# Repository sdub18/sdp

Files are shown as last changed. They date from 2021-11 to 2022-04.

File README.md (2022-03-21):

# Senior Design Project UMass Electrical and Computer Engineering - Team 23
Motor Health Analytics and Feedback Dashboard
Sam DuBois, Andres Gutierrez, Andrew Tran, and Michael Brauninger

Packages Necessary to Download to Run Arduino Code
- Adafruit MCP9808
- Adafruit LIS3DH
- Adafruit INA260
- ArduinoJSON6




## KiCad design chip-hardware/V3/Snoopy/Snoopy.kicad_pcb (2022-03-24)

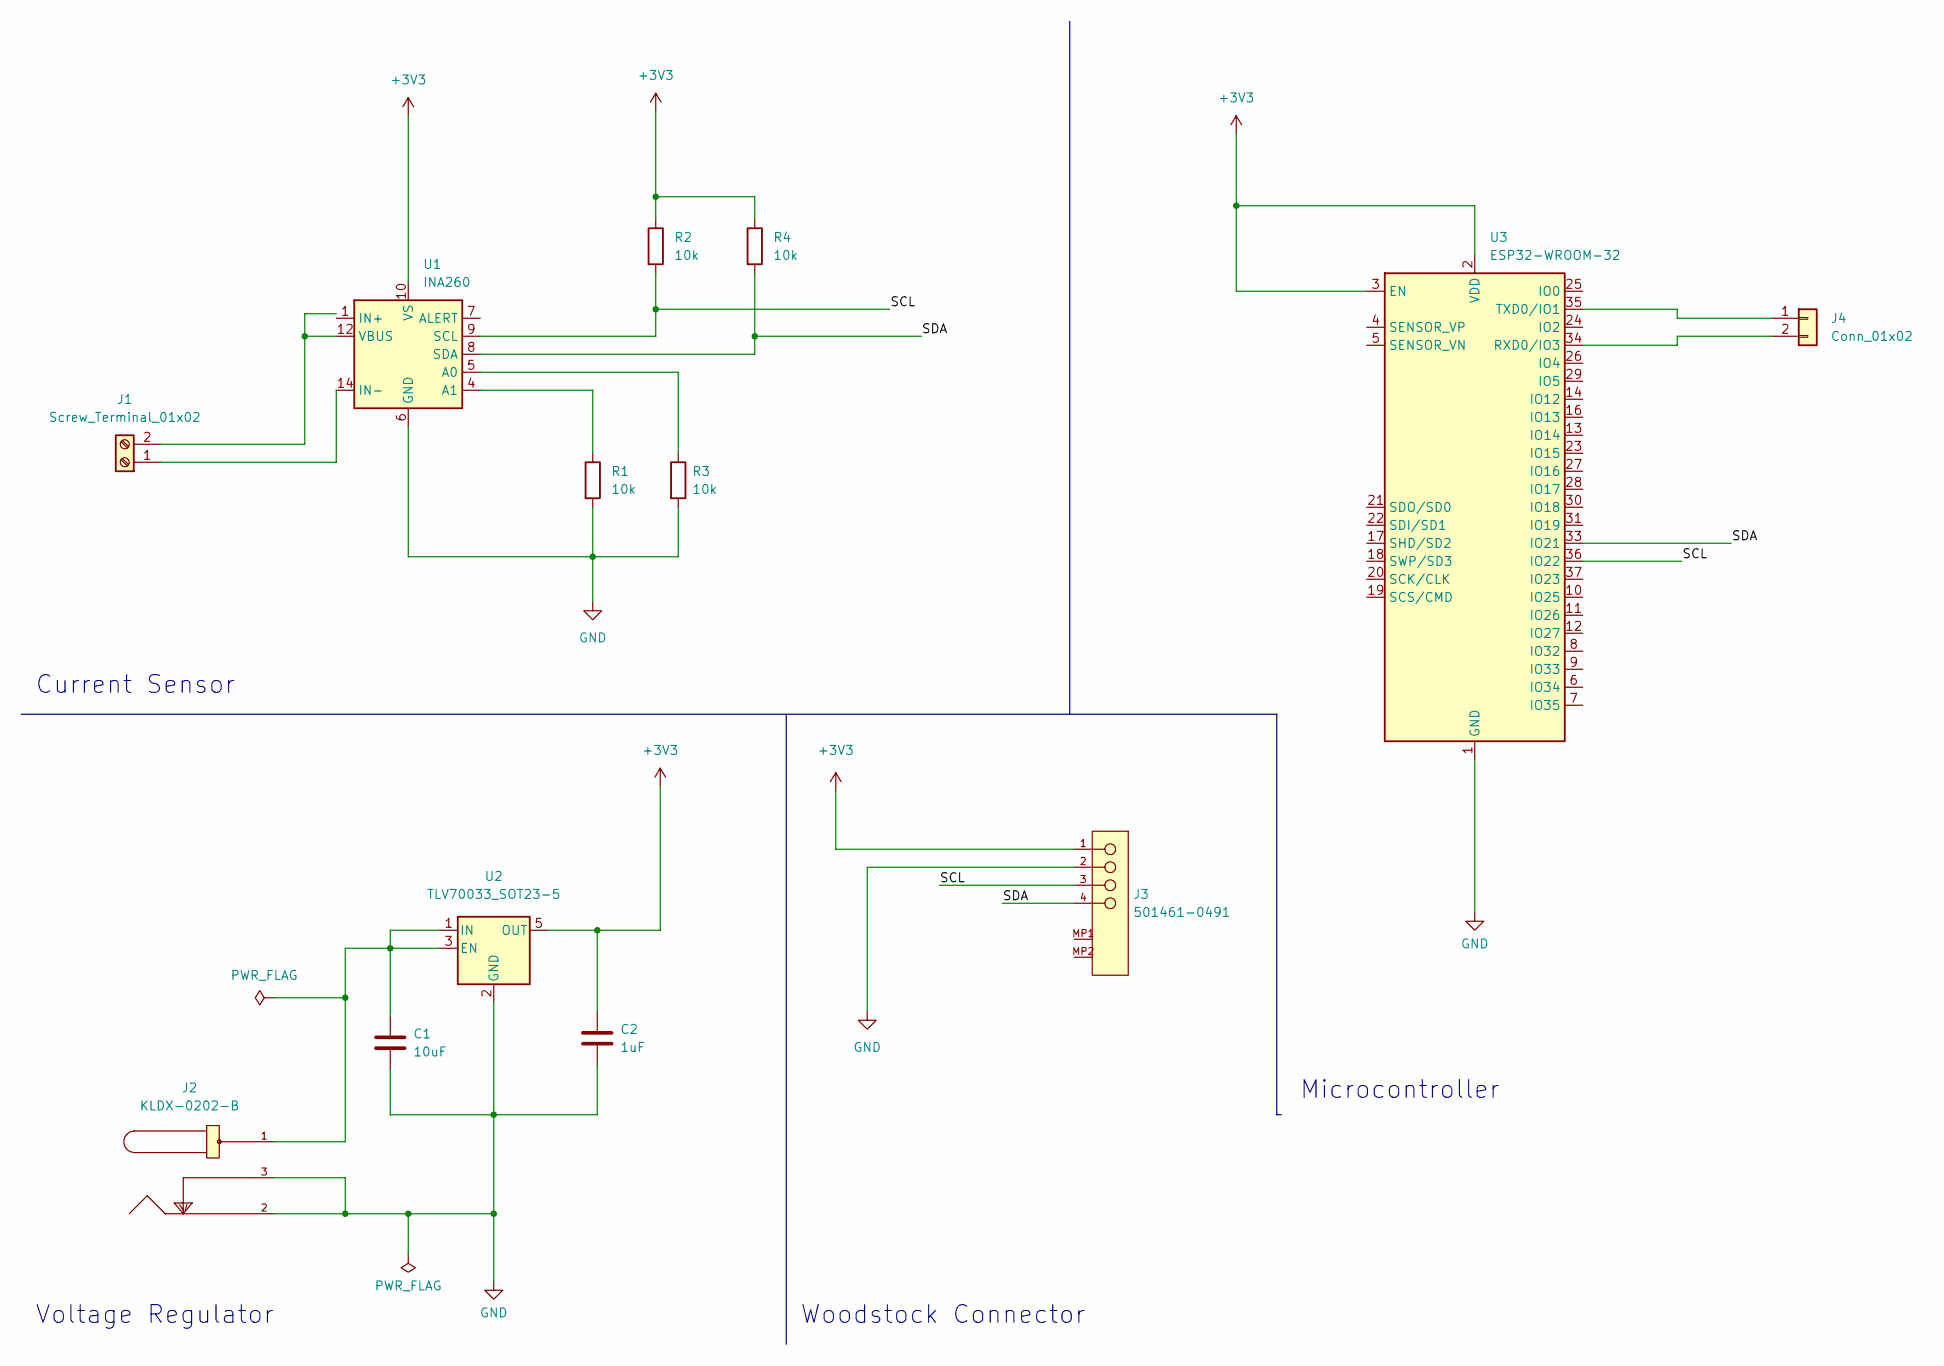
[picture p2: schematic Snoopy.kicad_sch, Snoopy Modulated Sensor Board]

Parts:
C1: 10uF; C_0603_1608Metric_Pad1.08x0.95mm_HandSolder
C2: 1uF; C_0603_1608Metric_Pad1.08x0.95mm_HandSolder
J1: Screw_Terminal_01x02; TerminalBlock_RND_205-00232_1x02_P5.08mm_Horizontal
J2: KLDX-0202-B; Kycon-KLDX-0202-B-MFG; current rating 3.5A; voltage rating 24V; mouser part number 806-KLDX-0202-B; digikey description CONN PWR JACK 2.5X5.5MM SOLDER
J3: 501461-0491; Molex-501461-0491-Manufacturer_Recommended; Voltage Max 50V AC (RMS)/DC
J4: Conn_01x02; SolderWire-0.1sqmm_1x02_P3.6mm_D0.4mm_OD1mm
R1, R2, R3, R4: 10k; R_0603_1608Metric_Pad0.98x0.95mm_HandSolder
U1: INA260; TSSOP-16_4.4x5mm_P0.65mm
U2: TLV70033_SOT23-5; SOT-23-5
U3: ESP32-WROOM-32

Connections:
+3V3: C2.1, J3.1, R2.1, R4.1, U1.10 (VS), U2.5 (OUT), U3.2 (VDD), U3.3 (EN)
/SCL: J3.3, R2.2, U1.9 (SCL), U3.36 (IO22)
/SDA: J3.4, R4.2, U1.8 (SDA), U3.33 (IO21)
GND: C1.2, C2.2, J2.2, J2.3, J3.2, R1.2, R3.2, U1.6 (GND), U1.11 (GND), U2.2 (GND), U3.1 (GND), U3.15 (GND), U3.38 (GND), U3.39 (GND)
unnamed: C1.1, J2.1, U2.1 (IN), U2.3 (EN)
unnamed: J1.1, U1.14 (IN-), U1.15 (IN-), U1.16 (IN-)
unnamed: J1.2, U1.12 (VBUS)
unnamed: J4.1, U3.35 (TXD0/IO1)
unnamed: J4.2, U3.34 (RXD0/IO3)
unnamed: R1.1, U1.4 (A1)
unnamed: R3.1, U1.5 (A0)
unnamed: U1.1 (IN+), U1.2 (IN+), U1.3 (IN+)

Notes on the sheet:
Voltage Regulator
Woodstock Connector
Microcontroller
Current Sensor

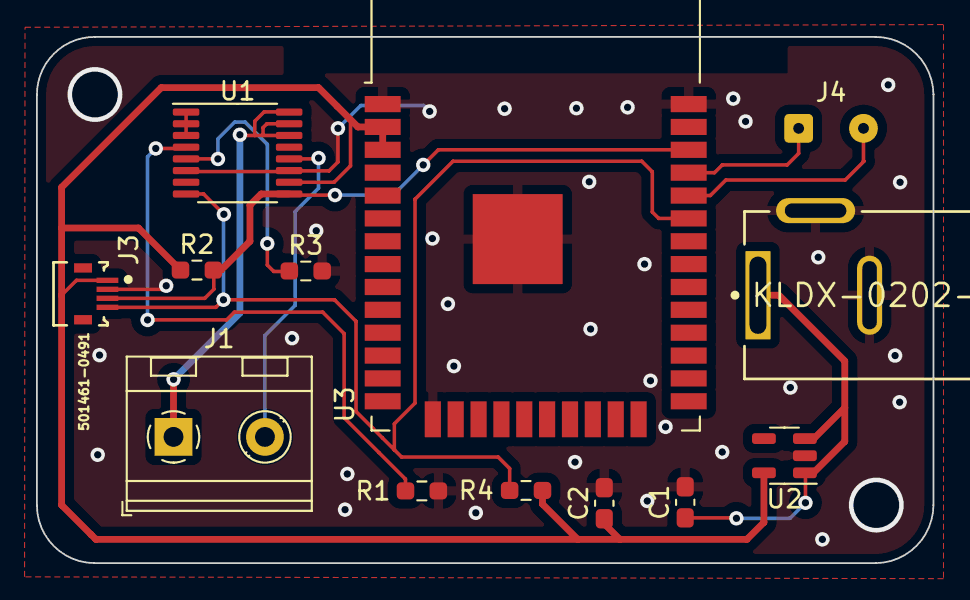
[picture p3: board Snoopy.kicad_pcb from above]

Board: 2 copper layers, 49.8 x 29.2 mm, 13 parts (0 on the bottom side), 12 nets.

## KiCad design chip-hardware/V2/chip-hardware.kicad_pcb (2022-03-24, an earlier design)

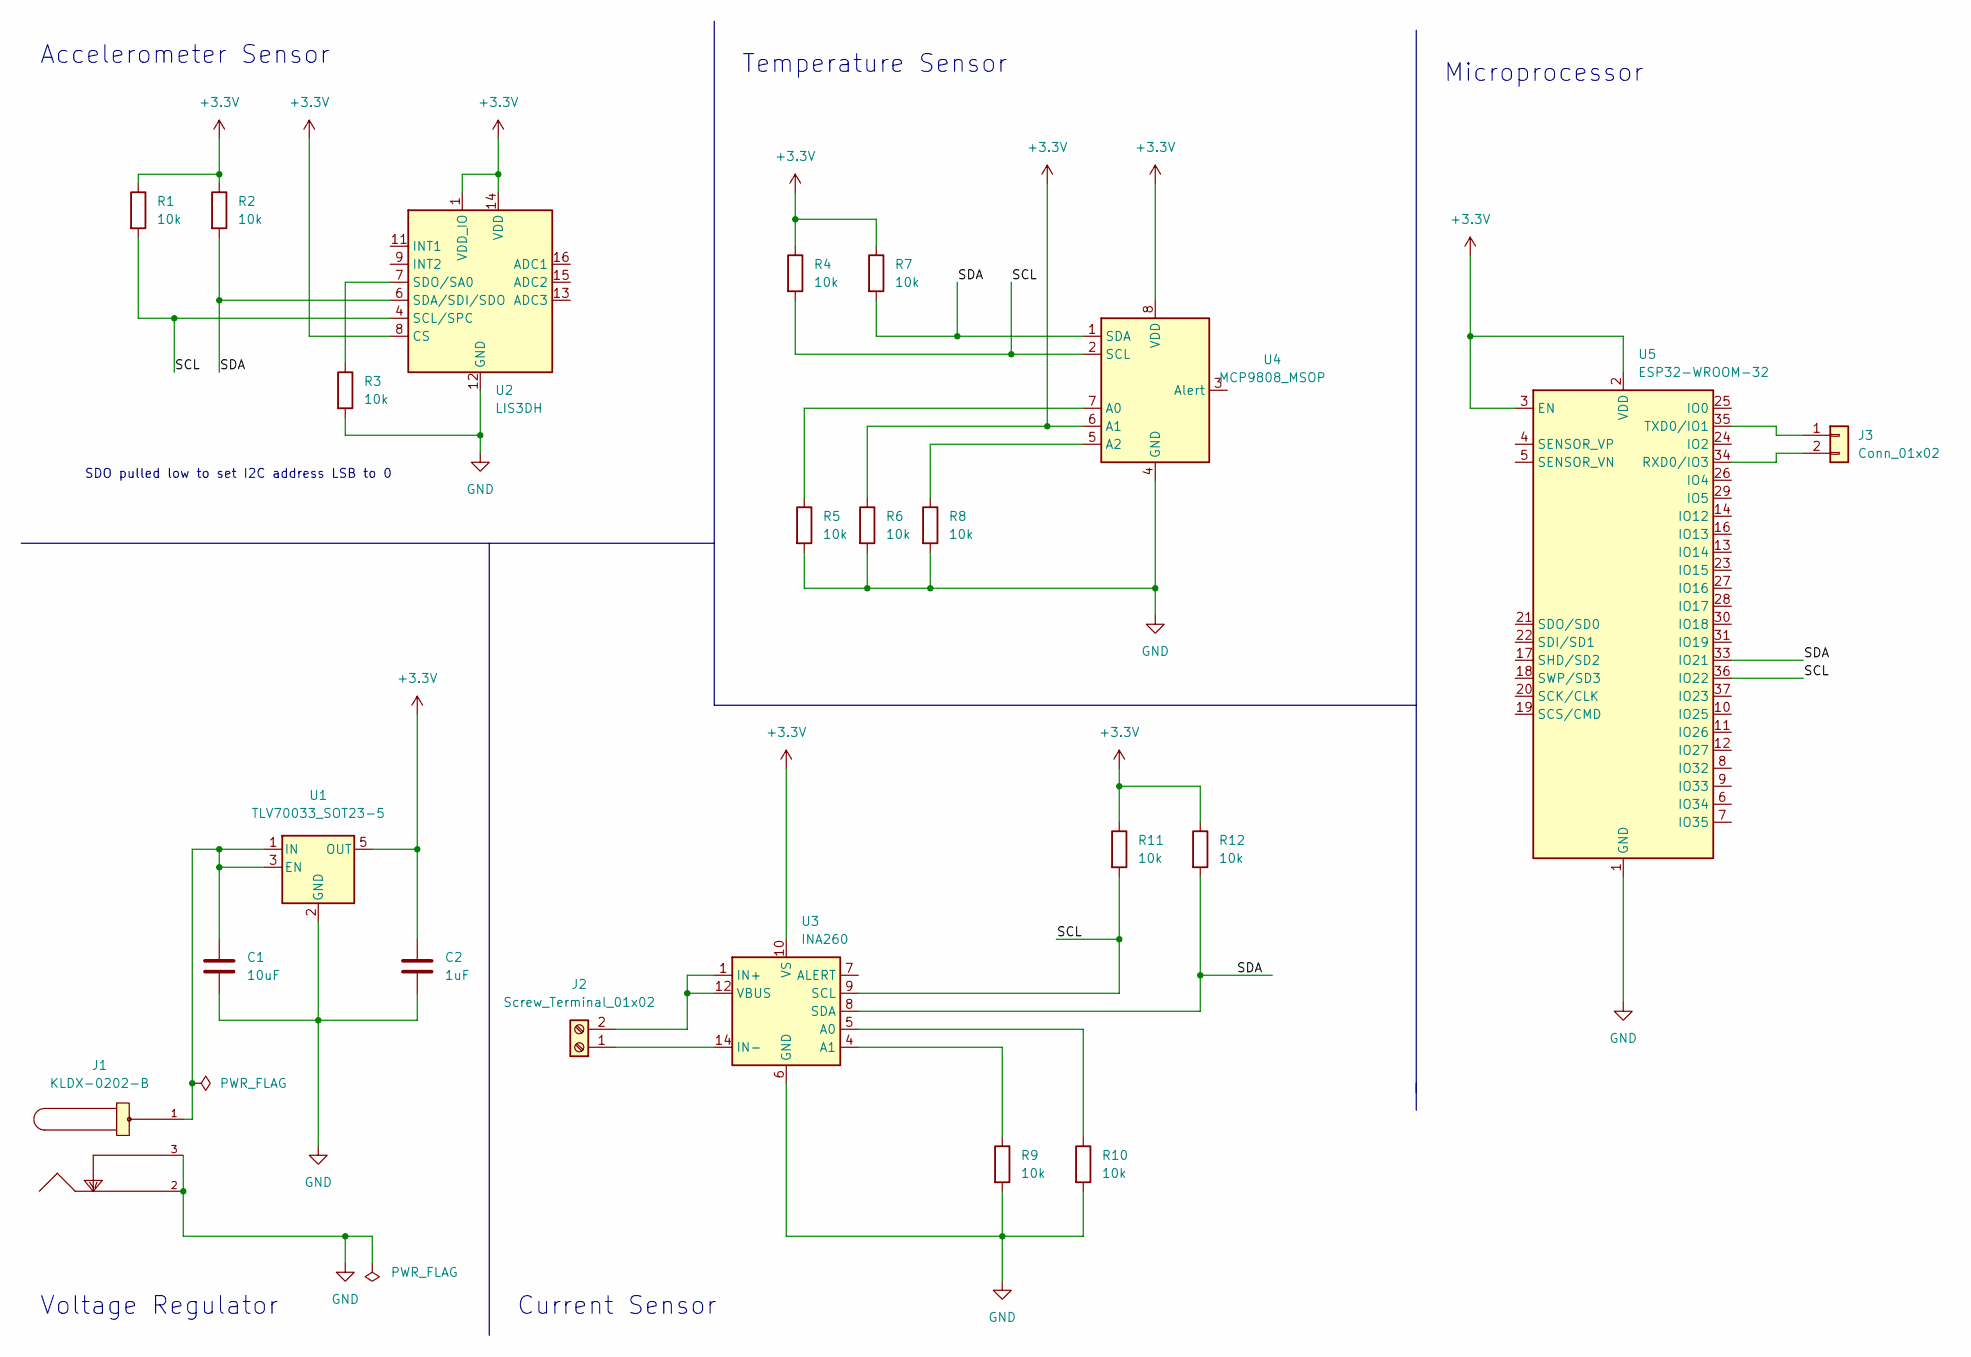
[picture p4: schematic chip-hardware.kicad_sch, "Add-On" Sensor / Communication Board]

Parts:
C1: 10uF; C_0603_1608Metric_Pad1.08x0.95mm_HandSolder
C2: 1uF; C_0603_1608Metric_Pad1.08x0.95mm_HandSolder
J1: KLDX-0202-B; Kycon-KLDX-0202-B-MFG; current rating 3.5A; voltage rating 24V; mouser part number 806-KLDX-0202-B; digikey description CONN PWR JACK 2.5X5.5MM SOLDER
J2: Screw_Terminal_01x02; TerminalBlock_RND_205-00232_1x02_P5.08mm_Horizontal
J3: Conn_01x02; SolderWire-0.1sqmm_1x02_P3.6mm_D0.4mm_OD1mm
R1, R2, R3, R4, R5, R6, R7, R8, R9, R10, R11, R12: 10k; R_0603_1608Metric_Pad0.98x0.95mm_HandSolder
U1: TLV70033_SOT23-5; SOT-23-5
U2: LIS3DH; LGA-16_3x3mm_P0.5mm_LayoutBorder3x5y
U3: INA260; TSSOP-16_4.4x5mm_P0.65mm
U4: MCP9808_MSOP; MSOP-8_3x3mm_P0.65mm
U5: ESP32-WROOM-32

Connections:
+3V3: C2.1, R1.1, R2.1, R4.1, R6.1, R7.1, R11.1, R12.1, U1.5 (OUT), U2.1 (VDD_IO), U2.8 (CS), U2.14 (VDD), U3.10 (VS), U4.6 (A1), U4.8 (VDD), U5.2 (VDD), U5.3 (EN)
/SCL: R1.2, R4.2, R11.2, U2.4 (SCL/SPC), U3.9 (SCL), U4.2 (SCL), U5.36 (IO22)
/SDA: R2.2, R7.2, R12.2, U2.6 (SDA/SDI/SDO), U3.8 (SDA), U4.1 (SDA), U5.33 (IO21)
GND: C1.2, C2.2, J1.2, J1.3, R3.2, R5.2, R6.2, R8.2, R9.2, R10.2, U1.2 (GND), U2.5 (GND), U2.10 (GND), U2.12 (GND), U3.6 (GND), U3.11 (GND), U4.4 (GND), U5.1 (GND), U5.15 (GND), U5.38 (GND), U5.39 (GND)
unnamed: C1.1, J1.1, U1.1 (IN), U1.3 (EN)
unnamed: J2.1, U3.14 (IN-), U3.15 (IN-), U3.16 (IN-)
unnamed: J2.2, U3.1 (IN+), U3.2 (IN+), U3.3 (IN+), U3.12 (VBUS)
unnamed: J3.1, U5.35 (TXD0/IO1)
unnamed: J3.2, U5.34 (RXD0/IO3)
unnamed: R3.1, U2.7 (SDO/SA0)
unnamed: R5.1, U4.7 (A0)
unnamed: R8.1, U4.5 (A2)
unnamed: R9.1, U3.4 (A1)
unnamed: R10.1, U3.5 (A0)

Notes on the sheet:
Current Sensor
Temperature Sensor
Microprocessor
Accelerometer Sensor
Voltage Regulator
SDO pulled low to set I2C address LSB to 0

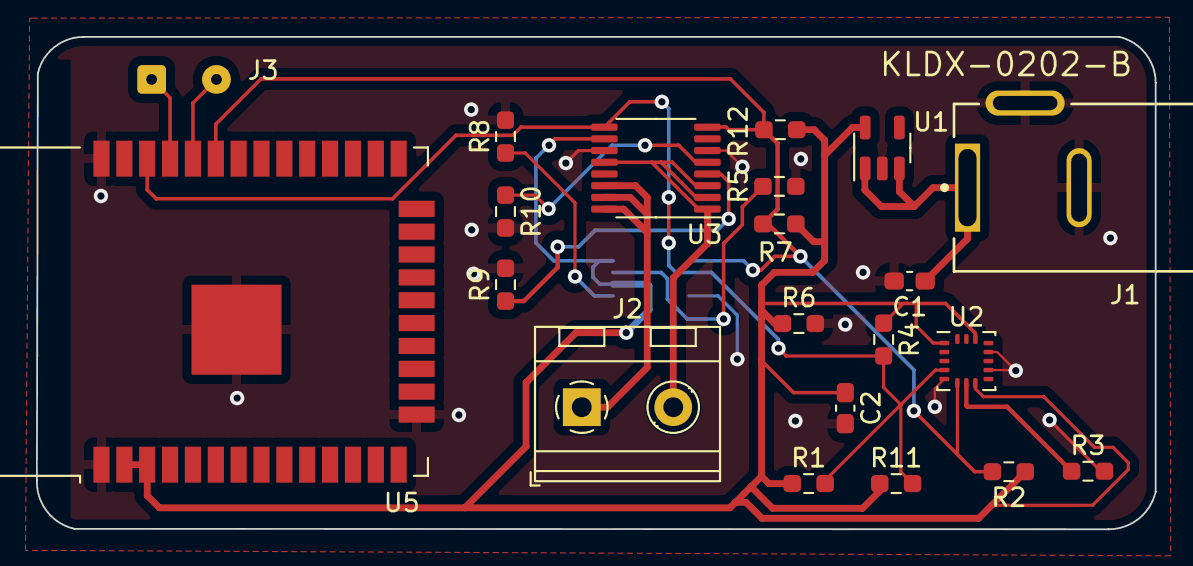
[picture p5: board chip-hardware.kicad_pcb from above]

Board: 2 copper layers, 62.2 x 27.4 mm, 22 parts (1 on the bottom side), 14 nets.

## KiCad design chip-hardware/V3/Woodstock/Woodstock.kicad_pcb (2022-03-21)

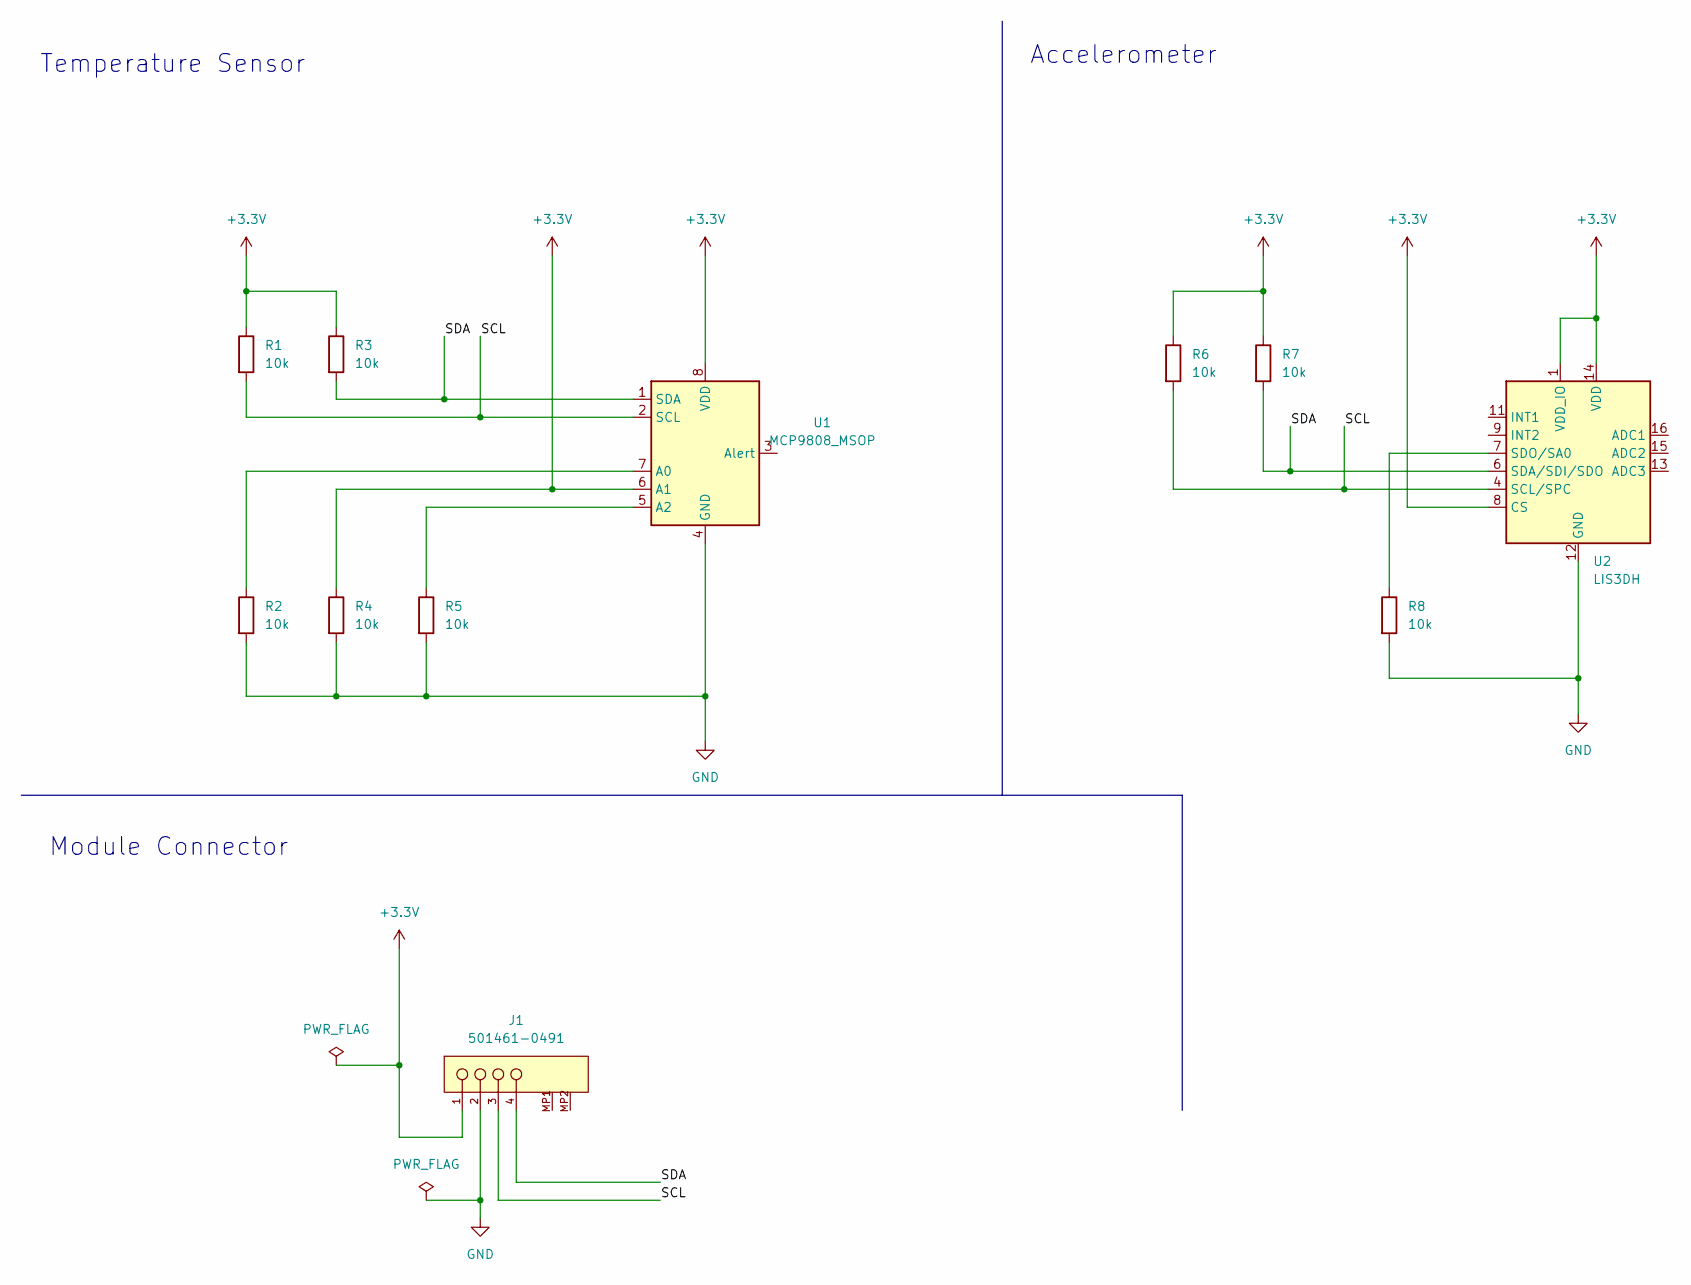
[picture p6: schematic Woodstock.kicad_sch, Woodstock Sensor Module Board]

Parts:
J1: 501461-0491; Molex-501461-0491-Manufacturer_Recommended; Voltage Max 50V AC (RMS)/DC
R1, R2, R3, R4, R5, R6, R7, R8: 10k; R_0603_1608Metric_Pad0.98x0.95mm_HandSolder
U1: MCP9808_MSOP; MSOP-8_3x3mm_P0.65mm
U2: LIS3DH; LGA-16_3x3mm_P0.5mm_LayoutBorder3x5y

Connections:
+3V3: J1.1, R1.1, R3.1, R4.1, R6.1, R7.1, U1.6 (A1), U1.8 (VDD), U2.1 (VDD_IO), U2.8 (CS), U2.14 (VDD)
/SCL: J1.3, R1.2, R6.2, U1.2 (SCL), U2.4 (SCL/SPC)
/SDA: J1.4, R3.2, R7.2, U1.1 (SDA), U2.6 (SDA/SDI/SDO)
GND: J1.2, R2.2, R4.2, R5.2, R8.2, U1.4 (GND), U2.5 (GND), U2.10 (GND), U2.12 (GND)
unnamed: R2.1, U1.7 (A0)
unnamed: R5.1, U1.5 (A2)
unnamed: R8.1, U2.7 (SDO/SA0)

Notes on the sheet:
Module Connector
Temperature Sensor
Accelerometer

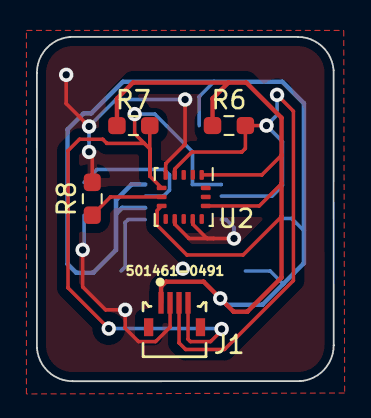
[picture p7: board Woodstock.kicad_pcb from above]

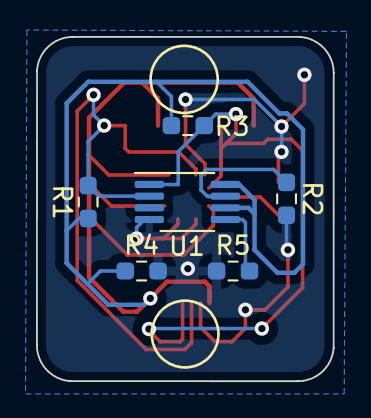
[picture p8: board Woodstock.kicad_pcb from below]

Board: 2 copper layers, 16.5 x 19.1 mm, 11 parts (6 on the bottom side), 7 nets.

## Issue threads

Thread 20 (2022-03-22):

Power Issue with Chip

sdub18, 2022-03-22:
Figure out why power readings were sometimes going to zero

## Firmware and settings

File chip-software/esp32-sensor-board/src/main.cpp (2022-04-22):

#include <Arduino.h>
#include <WiFi.h>
#include <Wire.h>
#include <Adafruit_MCP9808.h>
#include <Adafruit_LIS3DH.h>
#include <Adafruit_Sensor.h>
#include <Adafruit_INA260.h>
#include <ArduinoJson.h>
#include <StreamUtils.h>

const char* SSID = "Pixel_8846";   
const char* PASS = "andtran123";
const char* HOST = "192.168.180.57"; // change to ip address of host computer

const uint16_t PORT = 49160;
const uint16_t UID = 1;

uint16_t prevDay = 0;
bool canSend = false;
uint16_t sampleRate = 100;
// Json Document
StaticJsonDocument<16> id_pkt;
StaticJsonDocument<192> data_pkt;
JsonObject data = data_pkt.createNestedObject("data"); 
JsonObject acceleration = data.createNestedObject("acceleration");

// Connected Devices
Adafruit_LIS3DH lis3dh = Adafruit_LIS3DH();            // Accelerometer sensor
Adafruit_MCP9808 mcp9808 = Adafruit_MCP9808();   // Temperature Sensor
Adafruit_INA260 ina260 = Adafruit_INA260();         // Current Sensor

// WiFi Client to communicate with
WiFiClient client;
/////////////////////////////////////////////////////////////////////////////
// ------------------------- HELPER FUNCTIONS -----------------------------//
/////////////////////////////////////////////////////////////////////////////

void fetch_NTP() {
  configTime(0, 0, "pool.ntp.org");
}

int64_t get_timestamp() {
	struct timeval tv;
	gettimeofday(&tv, NULL);
	return (tv.tv_sec * 1000LL + (tv.tv_usec / 1000LL));
}

bool check_new_day(uint16_t *prev_day) {
  struct timeval tv;
	gettimeofday(&tv, NULL);
  int t = tv.tv_sec / 86400 ;
  if (t != *prev_day) {
    *prev_day = t;
    fetch_NTP();
    return true;
  }
  return false;
}

void create_packet() {
  // ---------- META DATA ------------------
  data_pkt["id"] = UID;
  data_pkt["timestamp"] = get_timestamp();

  // ---------- ACCELEROMETER ------------
  lis3dh.read();
  acceleration["x"] = lis3dh.x;
  acceleration["y"] = lis3dh.y;
  acceleration["z"] = lis3dh.z;


  // ----------- TEMPERATURE --------------
  data["temp"] = mcp9808.readTempF();
  
  // ------------- CURRENT ----------------
  data["current"] = ina260.readCurrent();
  data["voltage"] = ina260.readBusVoltage();
  data["power"] = ina260.readPower();

}


/////////////////////////////////////////////////////////////////////////////
// -------------------------- INITIAL SETUP -------------------------------//
/////////////////////////////////////////////////////////////////////////////


void setup() {
  // -------------------- SERIAL COMMUNICATIONS -----------------------
  Serial.begin(115200);
  while (!Serial) delay(1);

  id_pkt["id"] = UID;  

  // -------------------- WIFI CONNECTION -----------------------------
  WiFi.begin(SSID, PASS);
  while (WiFi.status() != WL_CONNECTED) {
      delay(500);
      Serial.println("Connecting to WiFi...");
  }
  Serial.println("Connected to the WiFi network");

  fetch_NTP(); // initialize time 

  // ------------------------ ACCELEROMETER -------------------------

  if (! lis3dh.begin(0x19)) {   // change this to 0x19 for alternative i2c address
    Serial.println("Could not start LIS3DH");
    while (1) yield();
  } else {
    Serial.println("LIS3DH started");
  }

  // ------------------------ TEMPERATURE ------------------------------
  
  if (!mcp9808.begin(0x1A)) {
    Serial.println("Could not start MCP9808");
    while (1);
  } else {
    Serial.println("MCP9808 started");
  }
  mcp9808.wake();
  mcp9808.setResolution(3); // sets the resolution mode of reading, the modes are defined in the table bellow:
  // Mode Resolution SampleTime
  //  0    0.5°C       30 ms
  //  1    0.25°C      65 ms
  //  2    0.125°C     130 ms
  //  3    0.0625°C    250 ms

  // --------------------------- CURRENT ------------------------------

  if (!ina260.begin()) {
    Serial.println("Could not start INA260");
    while (1);
  } else {
    Serial.println("INA260 started");
  }
  
}

/////////////////////////////////////////////////////////////////////////////
// ---------------------------- MAIN LOOP ---------------------------------//
/////////////////////////////////////////////////////////////////////////////

void loop() {

  if (client.connected()){
    // ------ check if new day -------------
    check_new_day(&prevDay);

    // ------ Check if server sent ACK ------
    if (client.available()) {
      if (!canSend){
        char c = client.read(); 
        if (c == 0x01) canSend = true;
      } else {
        char low = client.read();
        char high = client.read();
        sampleRate = (high << 8) | low;
      }
    }

    // -------- Communicate Results ---------
    WriteBufferingStream buffered_client(client, 192);
    if (canSend) {
      create_packet();
      serializeJson(data_pkt, Serial);
      Serial.println("");
      serializeJson(data_pkt, buffered_client);
      buffered_client.flush();
      delay(sampleRate);
    } else {
      serializeJson(id_pkt, Serial);
      Serial.println("");
      serializeJson(id_pkt, buffered_client);
      buffered_client.flush();
      delay(1000);
    }
    client.write("\n");

  } else {
    canSend = false;
    client.connect(HOST, PORT); 
  }
}

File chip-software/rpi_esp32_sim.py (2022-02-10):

#!/usr/bin/env python

import socket
import serial
import random
import time

class Transmitter:
	def __init__(self, HOST="localhost", PORT="4444"):
		self.host = HOST
		self.port = PORT
		
		self.buf = None
		self.ser_status = False
		self.sock_status = False

		self.init_ser()
		self.init_sock()
	
	def init_ser(self):
		self.ser = serial.Serial(
							port='/dev/serial0',
							baudrate = 115200,
							parity=serial.PARITY_NONE,
							stopbits=serial.STOPBITS_ONE,
							bytesize=serial.EIGHTBITS,
							timeout=5
						)
		self.ser_status = True
		print("serial connected!")
		self.ser.reset_input_buffer()

	def init_sock(self):
		self.sock = socket.socket(socket.AF_INET, socket.SOCK_STREAM)
		self.sock.connect((self.host, self.port))
		self.status = True
		print("C2M socket connected!\n")

	def read(self):
		self.buf = self.ser.readline()
		print(self.buf)

	def send(self):
		self.sock.send(self.buf)



def main():
	HOST = "192.168.1.3"
	PORT = 49160
	transmitter = Transmitter(HOST, PORT)
	while True:
		transmitter.read()
		transmitter.send()



if __name__ == "__main__":
	main()

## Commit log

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2021-11-07 Added basic graph and Material UI
2021-11-10 TCP client code for sensorboard
2021-11-11 added pthread.h for sensorboard client file
2021-11-21 Added title prop to Dynamic Graph
2021-11-21 ambient temp working with current
2021-11-22 comments on buttons/dropdown components
2021-11-23 config object to easily change chart props
2021-11-24 combined both M2F socket on connection handlers
2021-11-27 client_sim networking --> esp32 firmware
2021-11-28 Potentially helpful circuit python libraries
2021-11-28 Added code to get current sensor working
2021-11-28 Added code for accelerometer, temp sensor, and the combination of them both
2021-11-28 Added accelerometer isolated test
2021-11-28 Got all sensors working together
2021-11-29 sendFreq parameter for ESP32 data transmission
2021-11-29 Included PID in simulated client
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2021-12-02 Got UART communication working between raspberry pi and teensy
2021-12-02 Resolved small bugs with code. Ran tests and works great
    [MDR.ino]
2022-03-05 create timeout for sensorboard disconnet
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2022-03-05 update platformio (arduino) dependencies
2022-03-08 Reverting to commit before Andrews
    [MDR.ino, acceleromator_test.ino, current_sensor.ino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]
2022-03-08 Update to get everything on-track for moving frontend computation to backend
2022-03-09 hardware integration init fixes
    [main.cpp]
2022-03-13 created initial pcb files and folder location
    [chip-hardware.kicad_pcb, chip-hardware.kicad_sch]
2022-03-14 Added More components and wired up Accelerometer
    [chip-hardware.kicad_sch]
2022-03-14 Got temperature sensor working
    [chip-hardware.kicad_sch]
2022-03-14 Did almost all of the microprocessor, need to finish regulator
    [chip-hardware.kicad_sch]
2022-03-15 finished schematic drawing. Everything is looking really good so far
2022-03-15 Annotated all of the components. Everything looking good so far
    [chip-hardware.kicad_sch]
2022-03-15 Made a small positional change
    [chip-hardware.kicad_sch]
2022-03-15 Trying to remove warnings from chip
    [chip-hardware.kicad_sch]
2022-03-15 Removed the connection to power for the SDO pin. This means that the LSB will be set to the default address. No errors in the ECE
    [chip-hardware.kicad_sch]
2022-03-18 Added actual part associations for PCB, started work on PCB
    [chip-hardware.kicad_pcb, chip-hardware.kicad_sch]
2022-03-18 Added corner radius to the chip
    [chip-hardware.kicad_pcb]
2022-03-18 pulled in pretty format for new barrel jack connector
    [chip-hardware.kicad_sch]
2022-03-18 more placement of parts
    [chip-hardware.kicad_pcb]
2022-03-18 Got the traces mostly done. Just need to do some reviewing
    [chip-hardware.kicad_pcb]
2022-03-18 filled the zones
    [chip-hardware.kicad_pcb]
2022-03-18 fixing some buggs
    [chip-hardware.kicad_pcb]
2022-03-18 Fixed resistor sizing. Accidentally selected 204 and not 603s. Would have been IMPOSSIBLE to solder
    [chip-hardware.kicad_pcb, chip-hardware.kicad_sch]
2022-03-18 wired in all connecitions. Everything is looking good
    [chip-hardware.kicad_pcb]
2022-03-19 Circuit has no errors and looks good. Think it may be ready for submission
    [chip-hardware.kicad_pcb]
2022-03-19 Added changes to the pcb to fix some small layout issues with the LIS3DH chip
    [chip-hardware.kicad_pcb]
2022-03-19 filled out page settings
    [chip-hardware.kicad_pcb]
2022-03-19 Changed folder layout and setup projects for V2 and V3
    [Snoopy.kicad_pcb, Snoopy.kicad_sch, Woodstock.kicad_pcb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]
2022-03-19 started working on the second iteration of the schematic
    [Woodstock.kicad_sch]
2022-03-19 Added pwr flag
    [Woodstock.kicad_sch]
2022-03-19 All parts associated correctly and assigned to parts
    [Woodstock.kicad_sch]
2022-03-19 Components laid out on board
    [Woodstock.kicad_pcb]
2022-03-19 edge cuts introduced
    [Woodstock.kicad_pcb]
2022-03-19 Front traces added onto board
    [Woodstock.kicad_pcb]
2022-03-19 Added traces to the back.
    [Woodstock.kicad_pcb]
2022-03-19 Adjusted the PCB and fixed some errors with one of the chips
    [Woodstock.kicad_pcb]
2022-03-19 Connceted everything that needs to be connected. Looks good
    [Woodstock.kicad_pcb]
2022-03-19 fixed all errors and removed all warnings
    [Woodstock.kicad_pcb]
2022-03-19 placed some additional ias
    [Woodstock.kicad_pcb]
2022-03-19 Added the inital components to snoopy
    [Snoopy.kicad_sch]
2022-03-19 Finished layout of componets on sch
    [Snoopy.kicad_sch]
2022-03-19 Got the rest of the parts worked out
    [Snoopy.kicad_sch]
2022-03-19 Added pages settings
    [Snoopy.kicad_pcb]
2022-03-19 Started adding peices onto pcb
    [Snoopy.kicad_pcb]
2022-03-19 Added adjustment to the PCB. Everything seems right
    [Snoopy.kicad_pcb, Snoopy.kicad_sch, Woodstock.kicad_pcb]
2022-03-19 got placement down
    [Snoopy.kicad_pcb]
2022-03-19 finished second board with some minor errors
    [Snoopy.kicad_pcb]
2022-03-21 Created gerber files for all our parts so they can be uploaded to jlcpcb
    [Snoopy-B_Cu.gbr, Snoopy-B_Mask.gbr, Snoopy-B_Paste.gbr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]
2022-03-22 Added all the drill files and got everything fixced
    [Snoopy-NPTH.drl, Snoopy-PTH.drl, Woodstock-NPTH.drl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]
2022-03-23 Had to manually go in and modify the drill holes. not sure why they were like that but I think i fixed them. Gonna get the a-okay from chris first before sending them in
    [Snoopy.kicad_pcb]
2022-03-23 Created groud planes and fixed power jack issues. Issued new gerbers for both relevant files
    [Snoopy-B_Cu.gbr, Snoopy-B_Mask.gbr, Snoopy-B_Paste.gbr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]
2022-03-24 some hardware changes and the addition of the backend into the system
    [Snoopy-B_Cu.gbr, Snoopy-B_Mask.gbr, Snoopy-B_Paste.gbr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]
2022-04-04 fixed warning: key prop for list elements
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2022-04-06 added trash button icon on policy component
2022-04-06 INSERT functionality into DB
2022-04-06 fix data packet structure on firmware
    [main.cpp]
2022-04-06 include all data packet values in db insert
2022-04-09 change add policy button to be smaller
2022-04-09 update props callback names
2022-04-10 implement props destructing for readability
2022-04-12 testing socket bottleneck issues
2022-04-12 fixed socket rerender bottleneck -> still slow
2022-04-12 fix rerender bottleneck with new socket context
2022-04-12 implement new button compopnents
2022-04-12 fixed backend bottleneck -> db insert
2022-04-12 normalize server socket event names
2022-04-12 update HealthMonitor to fit socket context changes
2022-04-12 implement insert transaction to handle bottleneck
2022-04-18 add timestamp functionality to sensor boards
2022-04-18 on ECONNRESET -> reset canSend flag
    [main.cpp]
2022-04-18 update INSERT -> use timestamp from sensing board
2022-04-19 Fix insertNewPolicy issue
2022-04-20 remove config received by socket
2022-04-20 remove updateConfig handler from socketcontext
2022-04-20 Changes to the schematic
2022-04-22 Pushing up new file for running the esp code through arduino instead of platform.io
2022-04-22 period selection changes samplerate in module
2022-04-22 update server so sampleRate sent to modules
2022-04-22 sends sampleperiod to sensing modules
2022-04-27 fix voltage units
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
